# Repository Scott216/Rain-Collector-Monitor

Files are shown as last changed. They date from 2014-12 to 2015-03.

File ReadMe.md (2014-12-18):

Rain Collector

Outside board is panStamp plugged into a PCB which monitors temp of two heating pads, temp inside rain collector and temp below rain collector.  It also monitors pulses from rain collector and closes a relay for every pulse for the Davis Weather station.  Data is wirelessly sent to the panStamp on the inside.  The outside unit also turns on the heaters to melt the snow.  If outside temp is below freezing, heaters will come on for a few minutes.  If nothing melts to trip the water paddle, then heaters will turn off for a while.  If water is detected, heaters will stay on until all snow is melted.

The inside panStamp is connected to an Ethernet module which posts the data on Xively.
https://xively.com/feeds/103470/

As of 12/17/14 - the Rx sketch is compiled on Arduino IDE 1.5.8.  Some of the libraries need to be modified so the Ethernet SS pin can be assigned to a pin other then D10, because panStamp uses D10 to communicate with the radio.  The Tx sketch on the other hand is still compiled with Arduino 1.0.5, but needs to be updated to 1.5.8.

See [Arduino forum thread](http://forum.arduino.cc/index.php?topic=217423.msg1962182#msg1962182) and files regarding changing SS pin:

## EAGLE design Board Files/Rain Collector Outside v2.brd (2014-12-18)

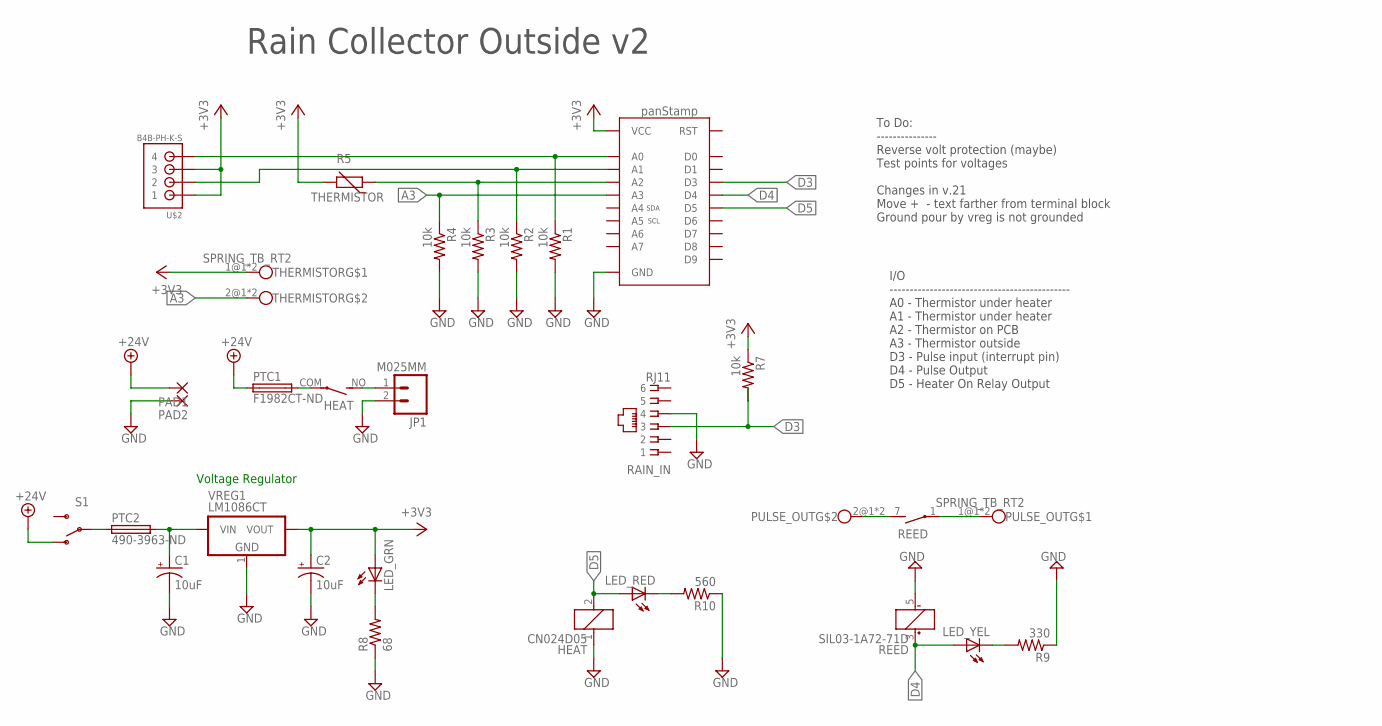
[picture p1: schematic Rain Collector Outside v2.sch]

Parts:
C1, C2: 10uF; CPOL-RADIAL-10UF-25V; PARTNO 478-6062-ND
HEAT: CN024D05; APF30212A; PARTNO CC1742-ND
JP1: M025MM; SCREWTERMINAL-5MM-2; PARTNO Sparkfun PRT-08432
LED_GRN: LED3MM
LED_RED: LED3MM
LED_YEL: LED3MM
PAD1, PAD2: 3,17/1,3
PANSTAMP: PANSTAMPNO_TEXT; PANSTAMP_NOTEXT
PTC1: F1982CT-ND; TE5; PARTNO F1982CT-ND
PTC2: 490-3963-ND; TE5; PARTNO 490-3963-ND
PULSE_OUT: SPRING_TB_RT2; PARTNO Sprakfun PRT-08073
R1, R2, R3, R4, R7: 10k; AXIAL-0.3; PARTNO RNF18FTD10K0CT-ND
R5: THERMISTOR; RS-2,5; PARTNO BC2301-ND
R8: 68; AXIAL-0.3; PARTNO CF18JT68R0CT-ND
R9: 330; AXIAL-0.3; PARTNO CF18JT330RCT-ND
R10: 560; AXIAL-0.3; PARTNO CF18JT560RCT-ND
RAIN_IN: RJ11; RJ11-NO_SHIELD; PARTNO A31406-ND
REED: SIL03-1A72-71D; REED; PARTNO 374-1322-ND
S1: SWITCH-SPDTPTH; SWITCH-SPDT; PARTNO EG1903-ND
THERMISTOR: SPRING_TB_RT2; PARTNO Sparkfun PRT-08073
U$2: B4B-PH-K-S; JST_B4B-PH_HEADER; PARTNO 455-1706-ND
VREG1: LM1086CT; TO-220V

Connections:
+3V3: C2.1 (+), LED_GRN.A, PANSTAMP.VCC, R5.2, R7.P$1 (1), THERMISTOR.1@1, THERMISTOR.1@2, U$2.P1 (1), U$2.P3 (3), VREG1.2 (VOUT)
+24V: PAD1.1, PTC1.1, S1.1 (O)
A0: PANSTAMP.A0, R1.P$1 (1), U$2.P4 (4)
A1: PANSTAMP.A1, R2.P$1 (1), U$2.P2 (2)
A2: PANSTAMP.A2, R3.P$1 (1), R5.1
A3: PANSTAMP.A3, R4.P$1 (1), THERMISTOR.2@1, THERMISTOR.2@2
D3: PANSTAMP.D3, R7.P$2 (2), RAIN_IN.3
D4: LED_YEL.A, PANSTAMP.D4, REED.3 (+)
D5: HEAT.2, LED_RED.A, PANSTAMP.D5
GND: C1.2 (-), C2.2 (-), HEAT.1, JP1.2, PAD2.1, PANSTAMP.GND$1 (GND), PANSTAMP.GND$7 (GND), PANSTAMP.GND$15 (GND), PANSTAMP.GND$23 (GND), PANSTAMP.GND$24 (GND), R1.P$2 (2), R2.P$2 (2), R3.P$2 (2), R4.P$2 (2), R8.P$1 (1), R9.P$1 (1), R10.P$1 (1), RAIN_IN.4, REED.5 (-), VREG1.1 (GND)
unnamed: PULSE_OUT.2@1, PULSE_OUT.2@2, REED.7 (S)
unnamed: PULSE_OUT.1@1, PULSE_OUT.1@2, REED.1
unnamed: HEAT.NO (S), JP1.1
unnamed: LED_GRN.K (C), R8.P$2 (2)
unnamed: LED_YEL.K (C), R9.P$2 (2)
unnamed: LED_RED.K (C), R10.P$2 (2)
unnamed: PTC2.1, S1.2
unnamed: C1.1 (+), PTC2.2, VREG1.3 (VIN)
unnamed: HEAT.COM, PTC1.2

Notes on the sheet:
I/O --------------------------------------------- A0 - Thermistor under heater A1 - Thermistor under heater A2 - Thermistor on PCB A3 - Thermistor outside D3 - Pulse input (interrupt pin) D4 - Pulse Output D5 - Heater On Relay Output
Voltage Regulator
To Do: --------------- Reverse volt protection (maybe) Test points for voltages Changes in v.21 Move + - text farther from terminal block Ground pour by vreg is not grounded
Rain Collector Outside v2

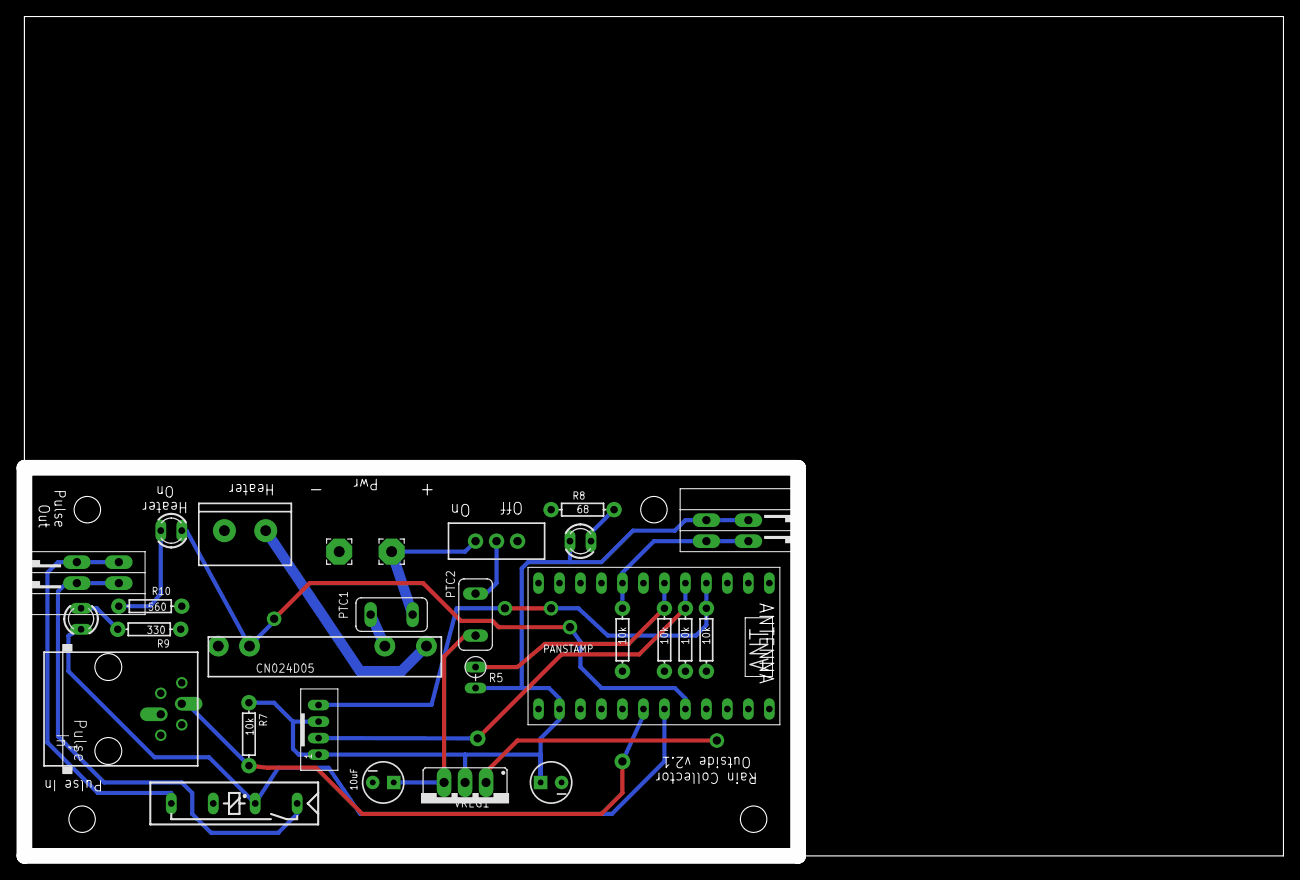
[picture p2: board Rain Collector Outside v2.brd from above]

Board: 2 copper layers, 152.4 x 101.6 mm, 28 parts (0 on the bottom side), 19 nets.

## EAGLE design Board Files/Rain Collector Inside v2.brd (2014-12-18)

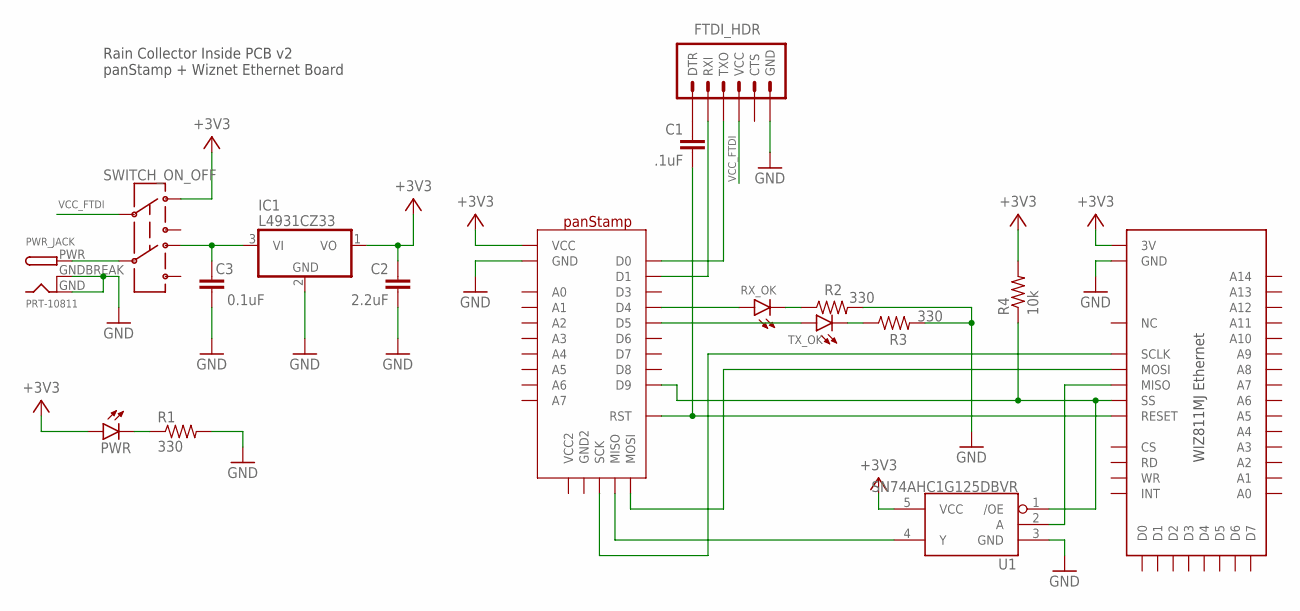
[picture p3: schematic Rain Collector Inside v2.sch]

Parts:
C1: .1uF; CAP-PTH-5MM
C2: 2.2uF; CAP-PTH-5MM
C3: 0.1uF; CAP-PTH-5MM
FTDI_HDR: ARDUINO_SERIAL_PROGRAMLONGPADS; 1X06_LONGPADS
IC1: L4931CZ33; TO92
PANSTAMP: PANSTAMP_SPI
PWR: LED5MM
PWR_JACK: PRT-10811; DCJACK_2MM_PTH
R1, R2, R3: 330; AXIAL-0.4
R4: 10k; AXIAL-0.4
RX_OK: LED5MM
SWITCH_ON_OFF: 401-2001-ND; SWITCH_DPDT_PTH
TX_OK: LED5MM
U1: SN74AHC1G125DBVR; SOT23-5
U$2: WIZ811MJ

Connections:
+3V3: C2.1, IC1.1 (VO), PANSTAMP.VCC, PWR.A, R4.P$2 (2), SWITCH_ON_OFF.1, U1.5 (VCC), U$2.3V@1 (3V), U$2.3V@2 (3V)
DTR: C1.1, FTDI_HDR.1 (DTR)
GND: C2.2, C3.2, FTDI_HDR.6 (GND), IC1.2 (GND), PANSTAMP.GND$1 (GND), PANSTAMP.GND$7 (GND), PANSTAMP.GND$15 (GND), PANSTAMP.GND$23 (GND), PANSTAMP.GND$24 (GND), PWR_JACK.GND, PWR_JACK.GNDBREAK, R1.P$2 (2), R2.P$2 (2), R3.P$2 (2), U1.3 (GND), U$2.GND@1 (GND), U$2.GND@2 (GND), U$2.GND@3 (GND), U$2.GND@4 (GND), U$2.GND@5 (GND)
GND2: PANSTAMP.GND2
MISO: PANSTAMP.MISO, U1.4 (Y)
MOSI: PANSTAMP.MOSI, U$2.MOSI
unnamed: FTDI_HDR.3 (TXO), PANSTAMP.D0
unnamed: FTDI_HDR.2 (RXI), PANSTAMP.D1
unnamed: PWR_JACK.PWR, SWITCH_ON_OFF.5
unnamed: PWR.K (C), R1.P$1 (1)
unnamed: U1.2 (A), U$2.MISO
unnamed: R2.P$1 (1), RX_OK.K (C)
unnamed: R3.P$1 (1), TX_OK.K (C)
unnamed: C3.1, IC1.3 (VI), SWITCH_ON_OFF.4
RST: C1.2, PANSTAMP.RESET (RST), U$2.RESET
RXLED: PANSTAMP.D4, RX_OK.A
SCLK: PANSTAMP.SCK, U$2.SCLK
SS: PANSTAMP.D9, R4.P$1 (1), U1.1 (/OE), U$2.SCS (SS)
TXLED: PANSTAMP.D5, TX_OK.A
VCC2: PANSTAMP.VCC2
VCC_FTDI: FTDI_HDR.4 (VCC), SWITCH_ON_OFF.2

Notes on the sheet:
Rain Collector Inside PCB v2 panStamp + Wiznet Ethernet Board

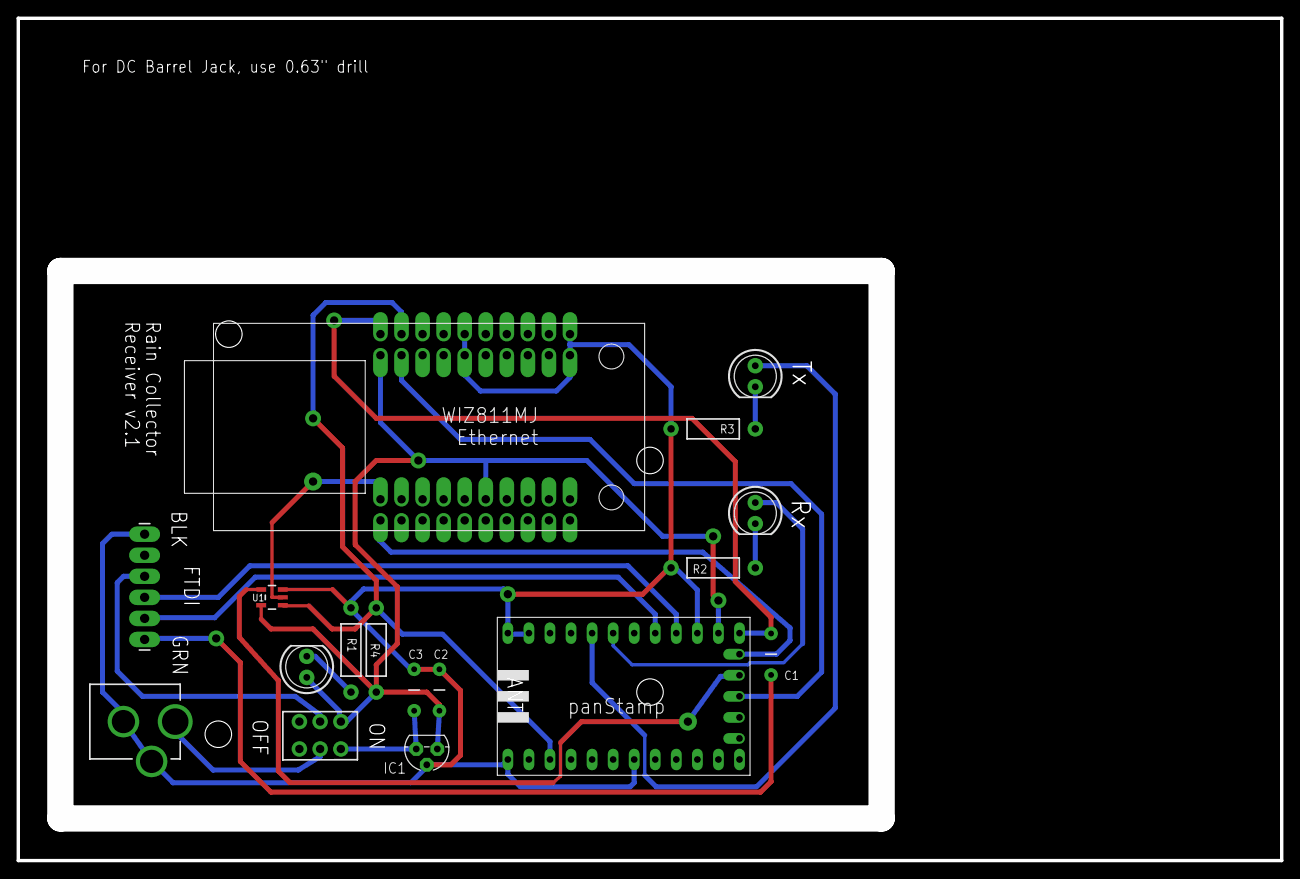
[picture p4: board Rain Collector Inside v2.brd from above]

Board: 2 copper layers, 152.4 x 101.6 mm, 17 parts (0 on the bottom side), 19 nets.

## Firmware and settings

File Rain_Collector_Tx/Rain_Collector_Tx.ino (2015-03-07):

/*
Rain collector heater 
Board: panStamp AVR  http://www.panstamp.com/product/panstamp-avr/
IDE Settings 1.6.x: 
Board: panStamp AVR

Xively Feed: http://xively.com/feeds/103470/

Function:
Measure 4 temperatures: 2 heating pads, inside rain collector, outside rain collector
Turn heater on/off
Receive and retransmit pulse from rain collector
Sends data to a panStamp inside the house which uploads to Xively

      
I/O:
A0 - Thermistor under heater
A1 - Thermistor under heater
A2 - Thermistor on PCB
A3 - Thermistor outside 
D3 - Pulse input (interrupt pin) 
D4 - Pulse Output 
D5 - Heater on output 

Panstamp Packet Structure
Byte   Function
----   ------------------------------------
 0      Rx address
 1      Tx Address
 2      Heater On/Off
 3,4    Pulse count
 5,6    Outside Temp
 7,8    Inside rain collector temp
 9,10   Heater 1 Temp
 11,12  Heater 2 temp

Notes:
Heat: 
If outside temp is less then 40 degrees, turn on every hour for several minutes to see if you get any pulses
If so, keep heat on until pulses stop for 1 your. 
If heaters get too hot, then cycle them until you can figure out the best voltage.
use a low pass filter on thermistors

Change Log:
09/12/14 v0.10 - Added version number
10/04/14 v0.11 - Use interrupt for pulse in. Moved global variables to loop() and made static.  Renamed Thermistor() to thermistorTempF().  
                 Only send data every 1/2 second. 
10/17/14 v0.12 - Changed networks address (syncword)to two byte array
10/18/14 v0.13 - Compiled with new version of panStamp libraries v2
12/25/14 v0.14 - Added setTxPowerAmp(). Uploaded to rain collector on 1/12/15
02/10/15 v0.15 - When outside temp is < 20, heater now stays on for 40 minutes, if > 20F, it's on for 15 minuts.
                 Also, renamed some variables and constants.
02/28/15 v2.00 - Upgraded code to use latest panStamp API.  Now both TX and Rx are up to date.  
03/03/15 v2.01 - Added RSSI Moved CCPACKET wirelessPacket to global area.  
*/

#define VERSION "v2.01"
#define PRINT_DEBUG     // comment this out to turn off serial printing

#include <Arduino.h>
#include <HardwareSerial.h> // Needed by Arduino IDE 1.6.x
#include <avr/wdt.h>        // http://github.com/simonz05/arduino-headers/blob/master/wdt.h

// Analog pins
const int8_t   PIN_TEMP_HOT1 =     0;  // Temp on heating pad 1
const int8_t   PIN_TEMP_HOT2 =     1;  // Temp on heating pad 2
const int8_t   PIN_TEMP_PCB =      2;  // Temp on PCB
const int8_t   TEMP_OUT =          3;  // Temp outside under rain collector
// Digital pins
const int8_t   PIN_PULSE_IN =      3;  // Rain pulse in
const int8_t   PIN_PULSE_OUT =     4;  // Rain pulse out to ISS on roof
const int8_t   PIN_HEATER_OUTPUT = 5;  // Relay to turn heaters on

const uint32_t ONEMIN =      60000UL;  // 1 minute in mS

volatile bool g_gotRainPulse = false;  // set by rainPulse() interrupt when rain bucket tips


// panStamp config
const byte g_RF_Channel =               0;  // panStamp channel
      byte g_psNetworkAddress[] = {10, 0};  // panStamp network address, aka SyncWord.  Tx and Rx must have same network address
const byte g_psSenderAddress =         41;  // panStamp outside Tx address
const byte g_psReceiverAddress =       40;  // panStamp inside Rx address

CCPACKET wirelessPacket;  // packet array of data to send to other indoor panStamp

// Function Prototypes
float thermistorTempF(int RawADC);
void rainPulse();  // Interrupt
void printPanstampDeviceInfo();

void setup()
{
  #ifdef PRINT_DEBUG
    Serial.begin(9600);
    delay(3000);
    Serial.print("Rain Collector Tx\nversion ");
    Serial.println(VERSION);
  #endif
  
  pinMode(PIN_PULSE_IN,         INPUT);
  pinMode(PIN_PULSE_OUT,       OUTPUT);
  pinMode(PIN_HEATER_OUTPUT,   OUTPUT);
  digitalWrite(PIN_PULSE_OUT,     LOW);
  digitalWrite(PIN_HEATER_OUTPUT, LOW);
  
  attachInterrupt(1, rainPulse, FALLING);  // Pin D3 interrupt for rain pulse

  // initialize panStamp radio
  panstamp.radio.setChannel(g_RF_Channel);
  panstamp.radio.setSyncWord(g_psNetworkAddress);  // Set network address, pointer to address
  panstamp.radio.setDevAddress(g_psSenderAddress);
  panstamp.radio.setTxPowerAmp(PA_LongDistance);  // Turns on high power mode. PA_LowPower is the default 
  
  #ifdef PRINT_DEBUG
    printPanstampDeviceInfo();  // print panStamp config
  #endif
  wdt_enable (WDTO_8S);  // 8 second timeout for WDT
} // end setup()


void loop()
{
  wdt_reset();  
  
  const uint32_t HEATER_ON_TIME =  30UL * ONEMIN; // Time heater stays on after last pulse detected (if it's cold outside)
  const uint8_t  HIGH_TEMP_LIMIT = 175;  // high temperature limit (F) for heaters

  static int16_t temp_PCB;
  static int16_t temp_Outside;
  static int16_t temp_Heater1;
  static int16_t temp_Heater2; 
  const double FILTERVAL = 0.01;  // used to smooth (average) temperature readings
  // Read therister temps, convert to F and smooth with low pass filter
  temp_PCB =      (thermistorTempF(analogRead(PIN_TEMP_PCB))  * (1-FILTERVAL)) + (FILTERVAL *     temp_PCB );
  temp_Outside =  (thermistorTempF(analogRead(TEMP_OUT))      * (1-FILTERVAL)) + (FILTERVAL * temp_Outside );
  temp_Heater1 =  (thermistorTempF(analogRead(PIN_TEMP_HOT1)) * (1-FILTERVAL)) + (FILTERVAL * temp_Heater1 );
  temp_Heater2 =  (thermistorTempF(analogRead(PIN_TEMP_HOT2)) * (1-FILTERVAL)) + (FILTERVAL * temp_Heater2 );
 
  static uint32_t heatOnDelay =    0;     // Delay so heater doesn't come back on too soon
  static uint32_t lastHeatOnTime = 0;     // Used to turn the heater on everyhour to see if any pulses start from melted snow
  static uint32_t lastPulseTime =  0;     // Used to see how long since the last pulse.  If heater is on an there are no pulses, then turn it off
  static bool     heatOnDelayTmrOneshot;  // Flag used with heater on delay timer
  static bool     hourlyCheckFlag;        // True if heater should come on for an hourly check to see if there is snow to melt.  
                                          // Heater should stay on for HEATER_ON_TIME 
  // See if heater should turn on
  bool is_cold_outside = temp_Outside < 40;
  bool inside_temp_not_too_hot = temp_PCB < 80;
  bool heat_pads_not_too_hot = (temp_Heater1 < HIGH_TEMP_LIMIT) && (temp_Heater2 < HIGH_TEMP_LIMIT);
  bool heat_timer_not_expired =  (((long)(millis() - lastPulseTime) < HEATER_ON_TIME) || hourlyCheckFlag == true);  
  bool heat_delay_has_passed = (long)(millis() - heatOnDelay) > 0;
  if ( is_cold_outside && heat_pads_not_too_hot && inside_temp_not_too_hot && heat_timer_not_expired && heat_delay_has_passed )
  {
    // Turn heaters on
    digitalWrite(PIN_HEATER_OUTPUT, HIGH);
    lastHeatOnTime = millis();
    heatOnDelayTmrOneshot = false;
  }
  else // turn heater off
  {
    digitalWrite(PIN_HEATER_OUTPUT, LOW); 
    // Only want heatOnDelay timer to be set once
    if (heatOnDelayTmrOneshot == false)
    { 
      heatOnDelay = millis() + 30000L;  // 30 second delay before heater can come back on again
      heatOnDelayTmrOneshot = true;
     }
  }

  // Turn on heater every hour to see if there is snow to melt
  static uint32_t hourlyCheckTimer = 0;   // used to keep heater on for a few minuts every hour
  if((long)(millis() -  lastHeatOnTime ) >= (ONEMIN * 60L) && hourlyCheckFlag == false )
  {
    hourlyCheckFlag = true;
    hourlyCheckTimer = millis();
  }

  // Reset hourly check flag.  This is where heater turns on once an hour to see if any snow melts.
  // If outside temp > 20F then reset after 15 minutes. If temp is < 20F, reset flag after 40 minutes
  uint32_t heater_on_time;
  if ( temp_Outside > 20 )
  { heater_on_time = ONEMIN * 15L; }
  else
  { heater_on_time = ONEMIN * 40L; }
  
  if( ((long)(millis() - hourlyCheckTimer ) >= heater_on_time ) && (hourlyCheckFlag == true) )
  { hourlyCheckFlag = false; }   

  // Reset rain pulse counter after 10 hours of no pulses
  static uint16_t pulseCount =  0;   // Pulse count, reset after 10 hours of no pulses
  const uint32_t TEN_HOURS = ONEMIN * 60UL * 10UL;
  if( (long)( millis() - lastPulseTime ) >= TEN_HOURS ) 
  { pulseCount = 0; }

  if ( g_gotRainPulse )
  {
    pulseCount++; 
    lastPulseTime = millis();

    // Turn on pulse out relay for 1/2 second
    digitalWrite(PIN_PULSE_OUT, HIGH);
    delay(500);
    digitalWrite(PIN_PULSE_OUT, LOW);
    
    g_gotRainPulse = false;  // reset 
  }

  // send data to inside panstamp
  static uint32_t sendDataTimer = millis();
  if( (long)(millis() - sendDataTimer) > 0 ) 
  {  
    
    wirelessPacket.length = 13;  // # bytes that make up packet to transmit
    uint8_t k = 0;
    wirelessPacket.data[k++] = g_psReceiverAddress;  // Address of panStamp Receiver that data is sent too (inside). First data byte has to be the destination address
    wirelessPacket.data[k++] = g_psSenderAddress;    // Address of this panStamp tranmsitter (outside)
    wirelessPacket.data[k++] = digitalRead(PIN_HEATER_OUTPUT);  // Heater on/off state 
    wirelessPacket.data[k++] = pulseCount >> 8 & 0xff;        
    wirelessPacket.data[k++] = pulseCount & 0xff;             
    wirelessPacket.data[k++] = temp_Outside >> 8 & 0xff;        
    wirelessPacket.data[k++] = temp_Outside & 0xff;             
    wirelessPacket.data[k++] = temp_PCB >> 8 & 0xff;         
    wirelessPacket.data[k++] = temp_PCB & 0xff;              
    wirelessPacket.data[k++] = temp_Heater1 >> 8 & 0xff;        
    wirelessPacket.data[k++] = temp_Heater1 & 0xff;             
    wirelessPacket.data[k++] = temp_Heater2 >> 8 & 0xff;        
    wirelessPacket.data[k++] = temp_Heater2 & 0xff;             
   
    bool sentStatus = panstamp.radio.sendData(wirelessPacket);  // transmit the data
    sendDataTimer = millis() + 500;  // add 500 mS to timer
    
    #ifdef PRINT_DEBUG
      if(sentStatus)
      {  // This does not mean the receiver successfully received the data
        Serial.print("Sent data success"); 
      } 
      else
      { Serial.println("Sent data failed"); }  
    #endif
  } // end send data
  
}  // end loop()


// return temp (F) for 10k thermistor 
float thermistorTempF(int RawADC) 
{
  float thermister;
  thermister = log(((10240000/RawADC) - 10000));
  thermister = 1 / (0.001129148 + (0.000234125 + (0.0000000876741 * thermister * thermister )) * thermister );
  thermister = thermister - 273.15;            // Convert Kelvin to Celsius
  thermister = (thermister * 9.0)/ 5.0 + 32.0; // Convert Celsius to Fahrenheit
  return thermister;
}  // end thermistorTempF()


void printPanstampDeviceInfo()
{
  // Print device setup info
  Serial.print(F("Radio Frequency = "));
  if(panstamp.radio.carrierFreq == CFREQ_868)
  { Serial.println(F("868 Mhz")); }
  else
  { Serial.println(F("915 Mhz")); }
  
  Serial.print(F("Channel = "));
  Serial.println(panstamp.radio.channel);
  Serial.print(F("Network address = "));
  Serial.println(panstamp.radio.syncWord[0]);
  Serial.print(F("Device address = "));
  Serial.println(panstamp.radio.devAddress);
  
}  // end printPanstampDeviceInfo()


// Interrupt routine, executed when pin D3 goes from HIGH to LOW
void rainPulse()
{
  g_gotRainPulse = true; 
}  // end rainPulse()

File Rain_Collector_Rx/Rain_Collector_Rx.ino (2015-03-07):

/*
To Compile (IDE 1.6.x).  Board = panStamp AVR

To Do:
Create new xivel feed and change channel IDs from numbers to text
Change from ERxPachube.h to Xively.h - maybe  http://github.com/xively/xively_arduino


Overview:
panStamp receives data from outside rain collector.  The data it receives is rain pulses (0.01" rain per pulse), heater on/off status and several temperatures. 
This data is then uploaded to Xively

Since both panstamp and Ethernet libary use pin D10 for slave select, some of the Ethernet libraries need to be modified to use a different pin.
SurferTim modified library files so Ethernet.select() would work:
Got new library from SurferTim here:  http://forum.arduino.cc/index.php?topic=217423.msg1962182#msg1962182

Difference between stock Arduino v1.5.8 original and SurferTim's are:
w5100.h      - https://www.diffchecker.com/2zzxtslg
w5100.cpp    - https://www.diffchecker.com/hl0s1zmd
Ethernet.h   - https://www.diffchecker.com/hwg0wq0p
Ethernet.cpp - https://www.diffchecker.com/6jdpzevk

Main Hardware:
 WIZ811MJ Ethernet module https://www.sparkfun.com/products/9473
 panStamp AVR  http://www.panstamp.com/product/panstamp-avr/


Xively Streams ( http://xively.com/feeds/103470 )
If you add a stream, you need to increase XIVELY_STREAMS
 0  Inches of rain.  Take pulses and divide by 10
 1  Heater On/Off
 2  Heating Pad 1 temp
 3  Heating Pad 2 temp
 4  Heating Pad 3 temp - future use
 5  Temp inside rain collector
 6  Outside temp
 7  Spare
 8  Xively upload successes
 9  Xively upload failures 
10  panStamp TxRx successes
11  Rx Status


Change Log:
09/13/14 v2.00 - Combined panStamp Rx and Base code together so panStamp can control Ethernet shield
10/04/14 v2.01 - Renamed a few things, some minor cleanup
10/17/14 v2.02 - Changed networks address (syncword)to two byte array
12/02/14 v2.03 - Compiled with IDE 1.5.8 and SurferTim modified libraries - doesn't work, hangs on Serial.println(Ethernet.localIP());
12/09/14 v2.04 - Added debugging code to find lockup problem.  Commented out Ethernet code and found it's hanging on radio.init().  Using stock Ethernet libraries
12/10/14 v2.05 - Updated for IDE 1.5.8 and panStamp API v2.0.  Finally got it working
01/09/15 v2.06 - Tx and Rx LED pins were reversed
02/02/15 v2.06 - Added new Xively channel for Rx status. 0 if not receiving data from outside, 1 if ok
02/28/15 v2.07 - changed some comments
03/03/15 v2.08 - Added RSSI 

*/

#define VERSION "v2.07"
// #define PRINT_DEBUG  // comment this out to turn off serial printing

#include <Arduino.h>
#include <SPI.h>             // http://arduino.cc/en/Reference/SPI
#include "HardwareSerial.h"  // Required by IDE 1.6.x
#include <ERxPachube.h>      // Library to upload to Xively  http://code.google.com/p/pachubelibrary/
#include <Ethernet.h>        // LIbrary for Arduino ethernet shield http://arduino.cc/en/Reference/Ethernet
#include <avr/wdt.h>         // Watchdog timer, Example code: http://code.google.com/p/arduwind/source/browse/trunk/ArduWind.ino
#include <Tokens.h>          //  Xively API Key


#define UPDATE_INTERVAL  20000   // Xively upload interval (mS) 
#define UPDATE_TIMEOUT  600000   // 10 minute timeout - if there are no successful updates in 10 minutes, reboot
uint32_t g_uploadTimout_timer = UPDATE_TIMEOUT; // Timer to reboot if no successful uploads in 10 minutes

// Xively Feed IDs
#define FEED_ID_TEST   4663  // Test feed  http://xively.com/feeds/4663
#define FEED_ID_RAIN 103470  // Rain Collector  http://xively.com/feeds/103470

ERxPachubeDataOut dataout_Rain(XIVELY_API_KEY, FEED_ID_RAIN);

const byte XIVELY_STREAMS = 12;

byte g_ip[] =  { 192, 168, 46, 83 };   // Suntec
// byte g_ip[] =  { 192, 168, 216, 40 };  // Crestview
byte g_mac[] = { 0xCC, 0xAC, 0xBE, 0x46, 0xFE, 0x99 }; 

// I/O
const byte ETH_SS_PIN =      9;  // Ethernet slave Select pin
const byte TX_OK_LED_PIN =   5;  // LED to flash when Xively upload succeeds
const byte RX_OK_LED_PIN =   4;  // LED to flash when panStamp packet is received

const byte g_RF_Channel =               0;  // panStamp channel
      byte g_psNetworkAddress[] = {10, 0};  // panStamp network address, aka SyncWord
const byte g_psReceiverAddress =       40;   // panStamp inside Rx address
      enum rx_status_t {RX_BAD, RX_GOOD};   // Status of packets received.
  uint32_t g_gotpsPacketTime =          0;   // Keeps track of time since last successful panStamp packet from rain collector
   uint8_t g_panStampSuccesses =        0;   // panStamp RxTx successes  
    int8_t g_rssi =                     0;   // panStamp signal strength
   
volatile boolean g_psPacketAvail = false;   // flag indicates a wireless panStamp packet has been received
 

// Variables to hold data coming from rain collector
int  g_tempIn;          // Temp inside rain collector
int  g_tempOut;         // Outdoor teamp
int  g_tempHeatPad1;    // Heating pad temp
int  g_tempHeatPad2;    // Heating pad temp
int  g_rainPulseCount;  // Rain gauges pulses, 1 pulse = 0.01" rain
bool g_isHeaterOn;      // True if heater on
bool g_TxOK;            // True if rain collector is transmitting


uint8_t g_xively_successes =  0;  // Successful Xively uploads
uint8_t g_xively_failures =   0;  // Xively Network failures


// Function Prototypes
void radioSignalInterrupt(void);
int  uploadRainCollector();
void checkXivelyStatus(int statusXively);
void BlinkLed(byte ledPin);
void PrintDataStream(const ERxPachube& pachube);
void printpanStampDeviceInfo();
void software_Reset();


// Routine to process interrupt from CC1101 (INT 0)
void radioSignalInterrupt(CCPACKET *psPacket)
{
  if( psPacket->crc_ok && psPacket->length > 1 )
  { 
    g_psPacketAvail = true; 
    g_gotpsPacketTime = millis(); // keep track of time since last good packet
    // Put packet data into global vairables
    //                  psPacket->data[0];    // Inside receiver address
    //                  psPacket->data[1];    // Outside transmitter address
    g_isHeaterOn =      psPacket->data[2];
    g_rainPulseCount =  psPacket->data[3] << 8;
    g_rainPulseCount |= psPacket->data[4];
    g_tempOut =         psPacket->data[5] << 8;
    g_tempOut |=        psPacket->data[6];
    g_tempIn =          psPacket->data[7] << 8;
    g_tempIn |=         psPacket->data[8];
    g_tempHeatPad1 =    psPacket->data[9] << 8;
    g_tempHeatPad1 |=   psPacket->data[10];         
    g_tempHeatPad2 =    psPacket->data[11] << 8;
    g_tempHeatPad2 |=   psPacket->data[12];
    g_rssi =            psPacket->rssi;
  } 

}  // end radioSignalInterrupt()
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

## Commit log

2014-12-18 Eagle Board Files
    Used Eagle 7.1. Outside PCB was made by fab house, Inside PCB was made
    by me on Shapeoko
    [Rain Collector Inside v2.brd, Rain Collector Inside v2.sch, Rain Collector Outside v2.brd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]
2014-12-25 v0.14 added high power setting
2015-02-28 v0.15 changed heating time
    Increased heater on time to 40 min if temp is < 20 degrees. Renamed
    some variables

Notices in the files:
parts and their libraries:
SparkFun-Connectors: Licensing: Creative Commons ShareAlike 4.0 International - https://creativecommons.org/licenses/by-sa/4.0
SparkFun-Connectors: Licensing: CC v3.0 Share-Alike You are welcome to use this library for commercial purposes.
